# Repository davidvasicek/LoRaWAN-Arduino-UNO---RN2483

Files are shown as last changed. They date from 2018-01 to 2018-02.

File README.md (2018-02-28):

# LoRaWAN-Arduino-UNO---RN2483

### Cíl projektu

Tento projekt byl vytvořen za účelem testování LoRaWAN sítě v oblasti Ostravy, kterou v rámci svých cvičení realizují studenti předmětu Radiokomunikační technika/Rádiové sítě vyučovaného na Katedře telekomunikační techniky, VŠB-TU Ostrava.

V rámci tohoto projektu bylo vytvořeno 8 čidel založených na deskách LoRaWAN Arduino UNO s čipem RN2483 napájených stabilizovaným 3V3 napětím devíti voltové externí baterie a integrovaným MicroUSB konektorem. Každý takovýto modul vysílá prostřednictvím LoRaWAN sítě o frekvenci 868 MHz krátký textový řetězec obsahující svou identifikaci, která je směrována na LoRa Gateway (TTN-GW-VSB) a vizualizována v prostředí The Things Network (TTN). Na základě této komunikace je následně možné určit vysílající výkonovou úrověň daných senzorů a tím vytvořit reálnou mapu pokrytí LoRaWAN sítě dané oblasti.

Pro účely testování bylo zapotřebí obejít Duty Cycle modulu RN2483, který nám omezoval zasílání zpráv v kratších intervalech. Každý takovýto modul RN2483 obsahuje vnitřní čítač zabraňující porušení vysílajících oprávnění přesahující 1% vysílající hodiny. Proto byl modul opakovaně resetován, čímž byl vymazán i jeho vnitřní čítač a tím jsme umožnili testování v kratších časových intervalech.

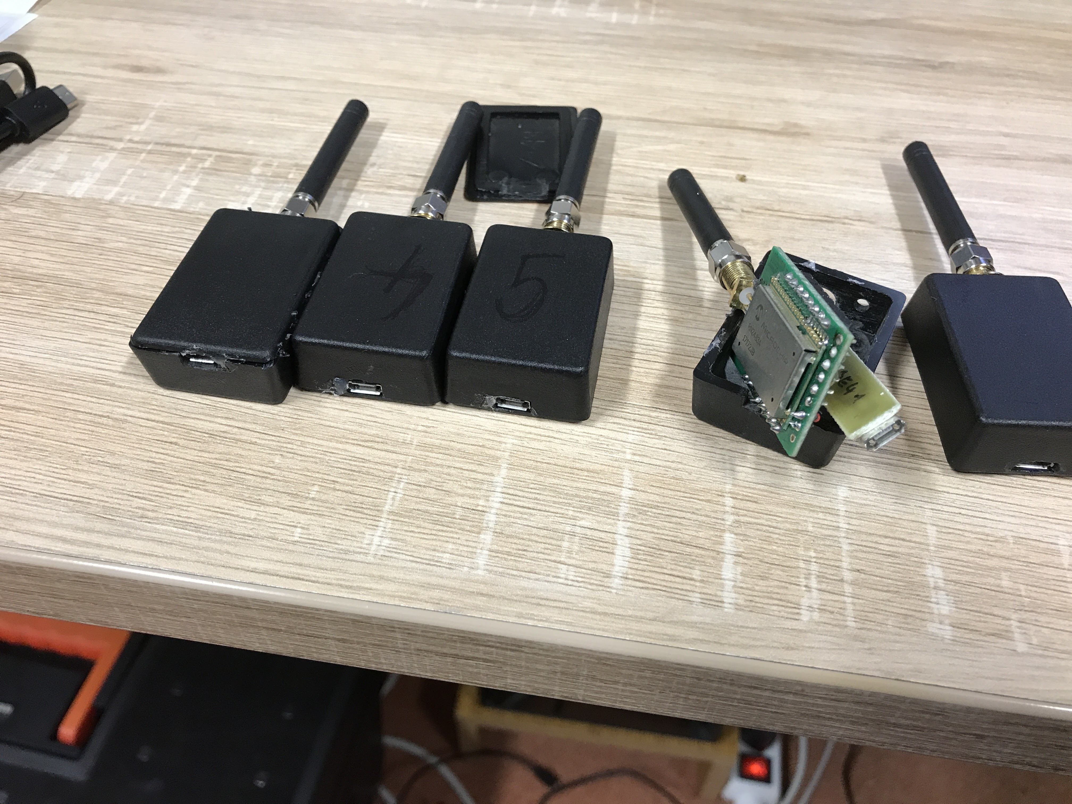
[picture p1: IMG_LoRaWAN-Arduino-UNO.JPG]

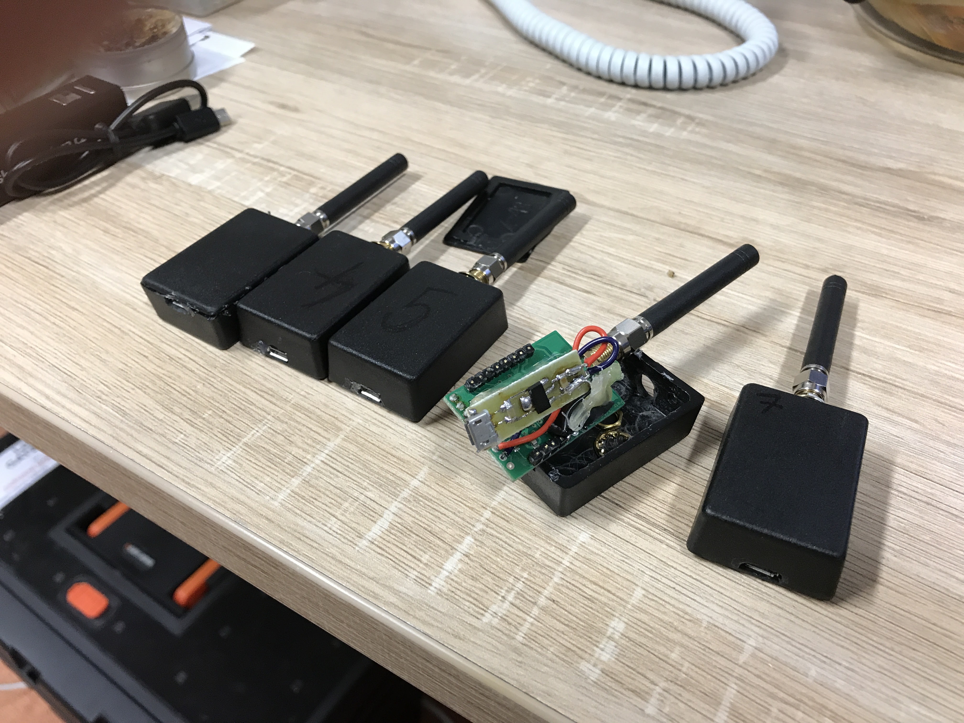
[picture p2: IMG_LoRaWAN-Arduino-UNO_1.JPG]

### Specifikace

LoRaWAN Arduino UNO je malý modulek, na jehož horní straně je transceiver RN2483 firmy Microchip, který je zkomunikovaný s procesorem ATmega328p ležícím na spodní straně desky. V procesoru je bootloader Arduino UNO (možno adaptovat na NANO). Modul je přímo přizpůsoben pro komunikaci v sítích LoRaWAN (více info na things.cz nebo na stránkách Českých Radiokomunikací a.s.). K dispozici jsou tato rozhraní: [1]
-	6 digitálních vstupů/výstupů
-	1 digitální vstup s přerušením pro low power režim
-	1 analogový vstup/výstup
-	vstup pro UART/USB převodník
-	anténní konektor SMA samice (na přání možno osadit U.FL IPX konektorem pro vyvedení antény pigtailem)

**Napájení:**
-	flash mód 5V
-	provozní mód 3,3V (bateriové napájení v rozmezí 2,4V až 4,1V)

**Naměřená spotřeba:**
-	power down mód cca 20uA
-	normální režim cca 25mA
-	vysílací špička cca 120mA

### Tutoriál

Výsledkem tohoto tutoriálu je čidlo založené na desce LoRaWAN Arduino UNO s vysílacím modulem RN2483 umožňující zasílaní krátkých zpráv prostřednictvím bezdrátové technologie LoRa. Tyto zprávy mohou obsahovat například informace o okolních teplotách získávány z externího teplotního senzoru, které je možné k desce LoRaWAN Arduino UNO připojit, nebo informace z mnoha jiných senzorů kompatibilních s touto deskou.

Kompletní tutoriál naleznete ve formátu .pdf [zde](https://github.com/davidvasicek/LoRaWAN-Arduino-UNO---RN2483/blob/master/LoRaWAN-Arduino-UNO---RN2483_tutorial.pdf)
                                                                                        
### Obsah adresáře

- **LoRa_RN5.brd** - DPS LoRaWAN Arduino UNO (Eagle)
- **LoRa_RN5.sch** - schéma LoRaWAN Arduino UNO (Eagle)
- **RN2483-Arduino-Library-master.zip** - knihovna pro RN2483 dostupná [zde](https://github.com/jpmeijers/RN2483-Arduino-Library)
- **LoRaWAN-Arduino-UNO---RN2483_code.ino** - kód pro Arduino IDE
- **LoRaWAN-Arduino-UNO---RN2483_tutorial.pdf** - tutoriál
- **LoRaDHT22** - ukázkový kód pro připojení teplotního čidla DHT22 k LoRaWAN Arduino UNO
- **IMG_LoRaWAN-Arduino-UNO.jpg** - foto vytvořených čidel
- **IMG_LoRaWAN-Arduino-UNO_1.jpg** - foto vytvořených čidel

### Užitečné odkazy

- Specifikace LoRaWAN Arduino UNO - RN2483 - e-shop [zde](https://www.arduinotech.cz/produkt/lorawan-arduino-uno/)
- Specifikace RN2483 [zde](http://ww1.microchip.com/downloads/en/DeviceDoc/50002346C.pdf)
- Popis technologie LoRa [zde](http://www.raycom.cz/data/article/filemanager/LoRa.pdf)
- Článek LPWAN - LoRaWAN, Sigfox - vítejte v IoT! [zde](https://www.arduinotech.cz/inpage/lpwan-lorawan-sigfox-vitejte-v-iot/)
- Článek LoRaWAN Arduino UNO s transceiverem RHF76 [zde](https://www.arduinotech.cz/inpage/lorawan-arduino-uno-s-transceiverem-rhf76/)

### Zdroje

- [1] [https://www.arduinotech.cz/produkt/lorawan-arduino-uno/](https://www.arduinotech.cz/produkt/lorawan-arduino-uno/)

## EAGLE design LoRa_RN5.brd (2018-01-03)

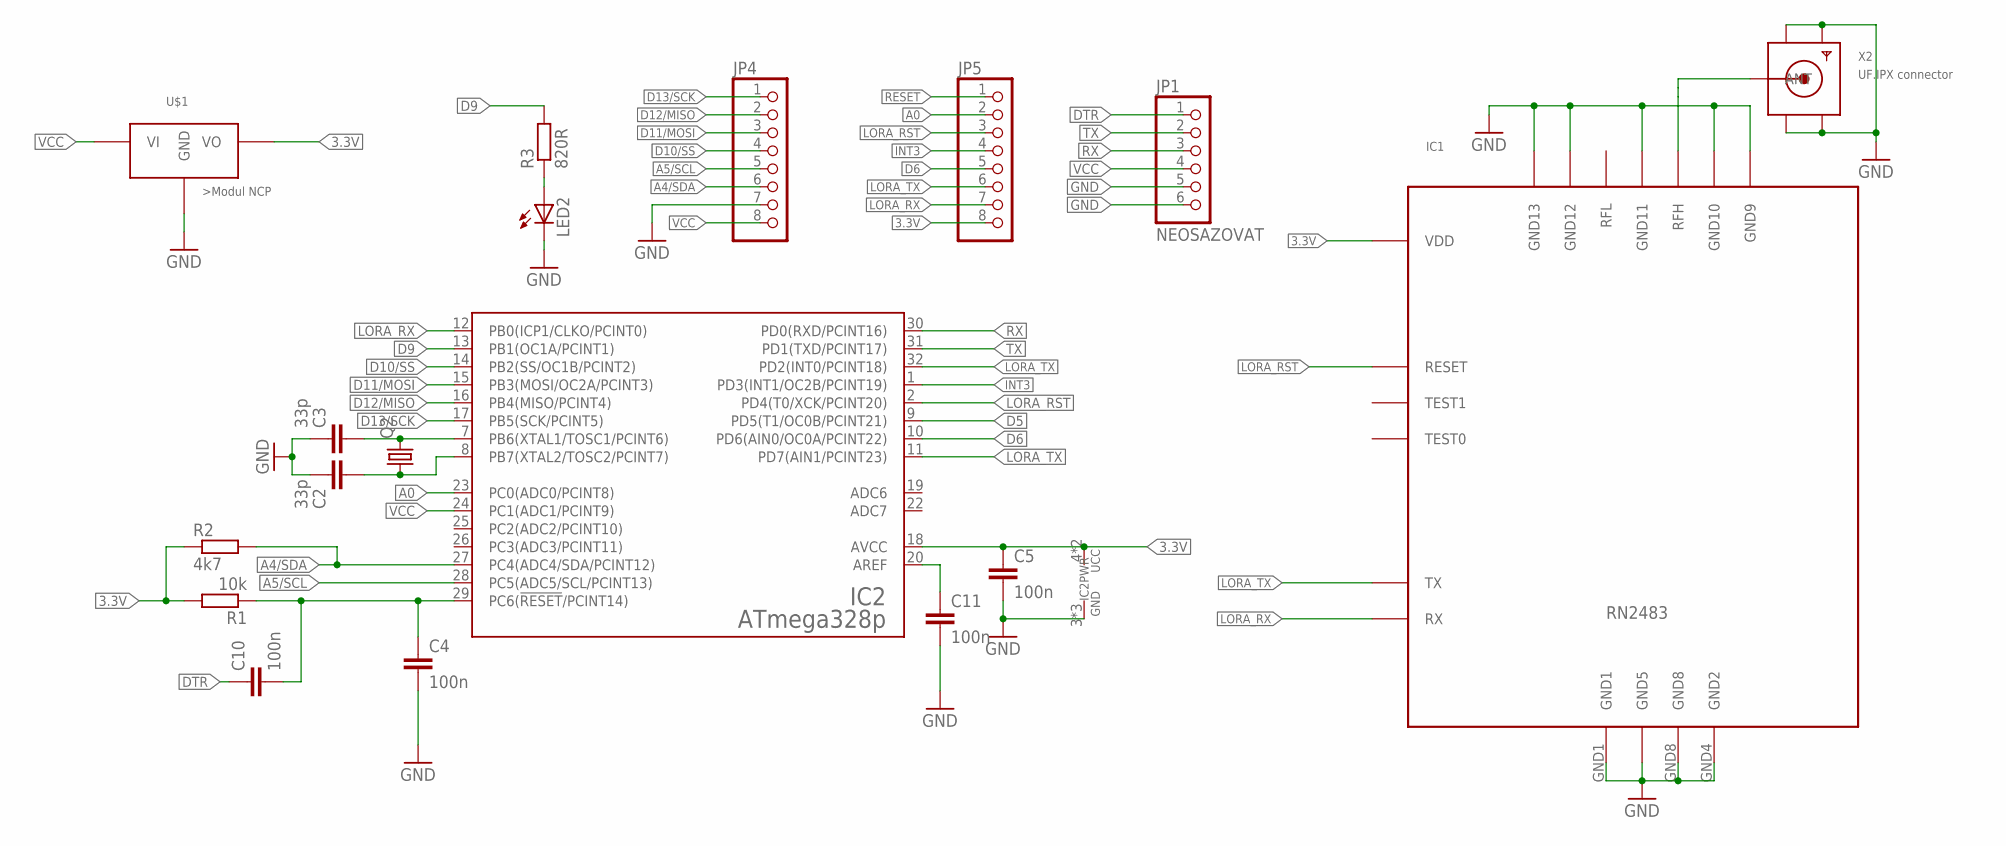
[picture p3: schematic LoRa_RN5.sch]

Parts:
C2, C3: 33p; C0805
C4, C5, C10, C11: 100n; C0805
IC1: RN2483_MIN; RN2483_2
IC2: ATmega328p; TQFP32-08
JP1: NEOSAZOVAT; 1X06
JP4, JP5: PINHD-1X8; 1X08
LED2: LEDCHIPLED_1206; CHIPLED_1206
Q2: CRYSTALCTS406; CTS406
R1: 10k; R0805
R2: 4k7; R0805
R3: 820R; R0805
U$1: NEOSAZOVAT; MOD_NCP1402
X2: UF.IPX connector; SMA_EDGELAUNCH_UFL

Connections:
3.3V: C5.1, IC1.VDD, IC2.4 (UCC), IC2.6 (UCC), IC2.18 (AVCC), JP5.8, R1.2, R2.1, U$1.VO
A0: IC2.23 (PC0(ADC0/PCINT8)), JP5.2
A4/SDA: IC2.27 (PC4(ADC4/SDA/PCINT12)), JP4.6, R2.2
A5/SCL: IC2.28 (PC5(ADC5/SCL/PCINT13)), JP4.5
D5: IC2.9 (PD5(T1/OC0B/PCINT21))
D6: IC2.10 (PD6(AIN0/OC0A/PCINT22)), JP5.5
D9: IC2.13 (PB1(OC1A/PCINT1)), R3.2
D10/SS: IC2.14 (PB2(SS/OC1B/PCINT2)), JP4.4
D11/MOSI: IC2.15 (PB3(MOSI/OC2A/PCINT3)), JP4.3
D12/MISO: IC2.16 (PB4(MISO/PCINT4)), JP4.2
D13/SCK: IC2.17 (PB5(SCK/PCINT5)), JP4.1
DTR: C10.1, JP1.1
GND: C2.1, C3.1, C4.2, C5.2, C11.2, IC1.GND1, IC1.GND4 (GND2), IC1.GND5, IC1.GND8, IC1.GND9, IC1.GND10, IC1.GND11, IC1.GND12, IC1.GND13, IC2.3 (GND), IC2.5 (GND), IC2.21 (GND), JP1.5, JP1.6, JP4.7, LED2.C, U$1.GND, X2.GND@1 (GND1), X2.GND@2 (GND2), X2.GND@3 (GND3), X2.GND@4 (GND4)
INT3: IC2.1 (PD3(INT1/OC2B/PCINT19)), JP5.4
LORA_RST: IC1.RESET, IC2.2 (PD4(T0/XCK/PCINT20)), JP5.3
LORA_RX: IC1.RX, IC2.12 (PB0(ICP1/CLKO/PCINT0)), JP5.7
LORA_TX: IC1.TX, IC2.11 (PD7(AIN1/PCINT23)), IC2.32 (PD2(INT0/PCINT18)), JP5.6
unnamed: IC1.RFH, X2.P (ANT)
unnamed: C2.2, IC2.8 (PB7(XTAL2/TOSC2/PCINT7)), Q2.1
unnamed: C3.2, IC2.7 (PB6(XTAL1/TOSC1/PCINT6)), Q2.3 (2)
unnamed: LED2.A, R3.1
unnamed: C11.1, IC2.20 (AREF)
RESET: C4.1, C10.2, IC2.29 (PC6(!RESET!/PCINT14)), JP5.1, R1.1
RX: IC2.30 (PD0(RXD/PCINT16)), JP1.3
TX: IC2.31 (PD1(TXD/PCINT17)), JP1.2
VCC: IC2.24 (PC1(ADC1/PCINT9)), JP1.4, JP4.8, U$1.VI

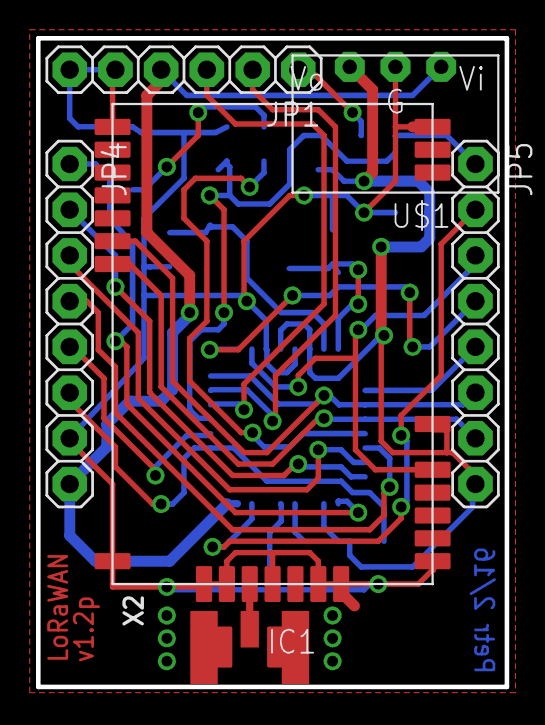
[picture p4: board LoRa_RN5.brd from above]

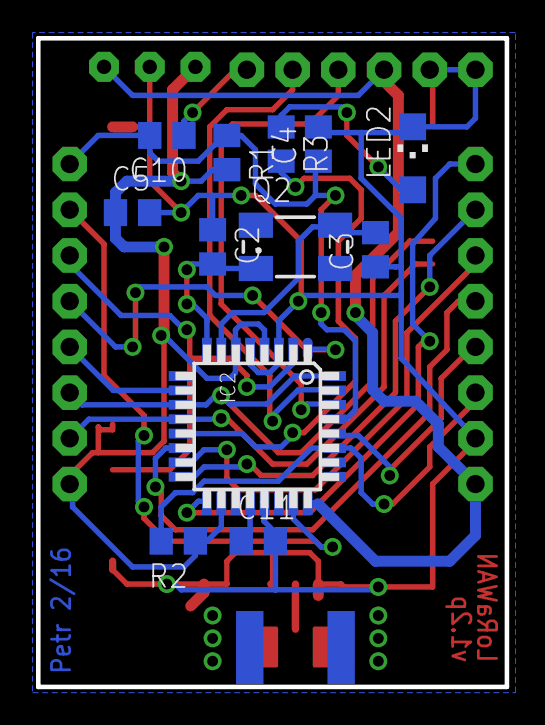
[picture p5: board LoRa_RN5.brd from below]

Board: 2 copper layers, 26.0 x 36.0 mm, 18 parts (12 on the bottom side), 25 nets.

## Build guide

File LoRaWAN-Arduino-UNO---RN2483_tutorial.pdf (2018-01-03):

## Tutoriál

# LoRaWAN Arduino UNO - RN2483

1) Připojení USB TTL (UART/FTDI) převodníku k desce LoRaWAN Arduino UNO

Z důvodu, že deska LoRaWAN Arduino UNO není osazena USB převodníkem, nelze ji přímo propojit s PC. Proto je nutné desku naprogramovat externím USB převodníkem, který slouží ke komunikaci mezi PC a zařízením s portem RS232 (sériové rozhraní), jinak také COM. Vhodný převodník je nutné volit tak, aby na něm byl přítomen DTR pin, potřebný pro RESET puls.

Tip: Pokud máte pouze USB převodník bez DTR pinu, mohli byste vytvořit RESETovací puls např. mikrospínacím tlačítkem (zapotřebí prostudovat).

Převodník lze zakoupit např. z těchto e-shopů:

- https://www.ptshop.cz/Prevodnik-USB-na-TTL-RS232-FTDI-FT232RL-d598.htm
- https://arduino-shop.cz/arduino/1747-breakout-board-usb-na-seriove-ic-ftdi-ft232rl-3-3v-5-5v-pro-arduino-1502365219.html (https://arduino-shop.cz/arduino/1747-breakout-board-usb-na-seriove-ic-ftdi-ft232rl-3-3v-5-5v-pro-arduino-1502365219.html)

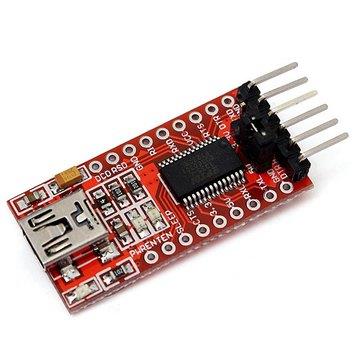
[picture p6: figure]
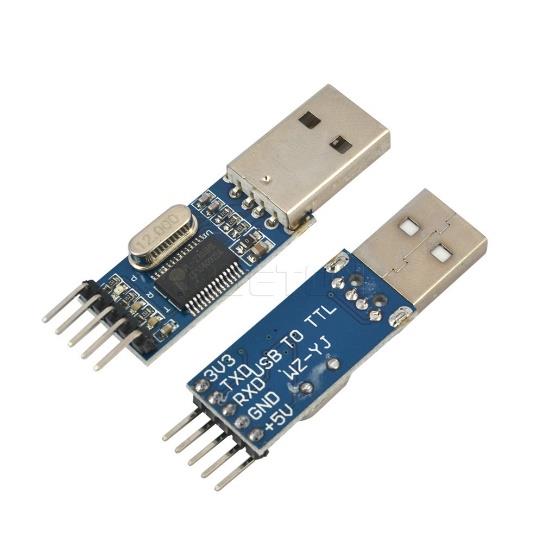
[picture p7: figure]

S DTR pinem | Bez DTR pinu
a) Připojte USB převodník k PC.
b) Spusťte správce zařízení (Start -> Ovládací panely -> Hardware a zvuk -> Správce zařízení) a zkontrolujte položku “Porty (COM a LPT)“, kde bychom měli najít námi připojené FTDI pod označením “COM(x)“, kde “x“ označuje číslo portu. Pokud takto označené FTDI nenajdeme, najdeme jej pravděpodobně v “Neznámá zařízení“ a to značí, že jej počítač neumí rozpoznat a budeme nuceni nainstalovat potřebné ovládače – bod c). Pokud PC převodník USB rozpoznal, přejděte k bodu d).

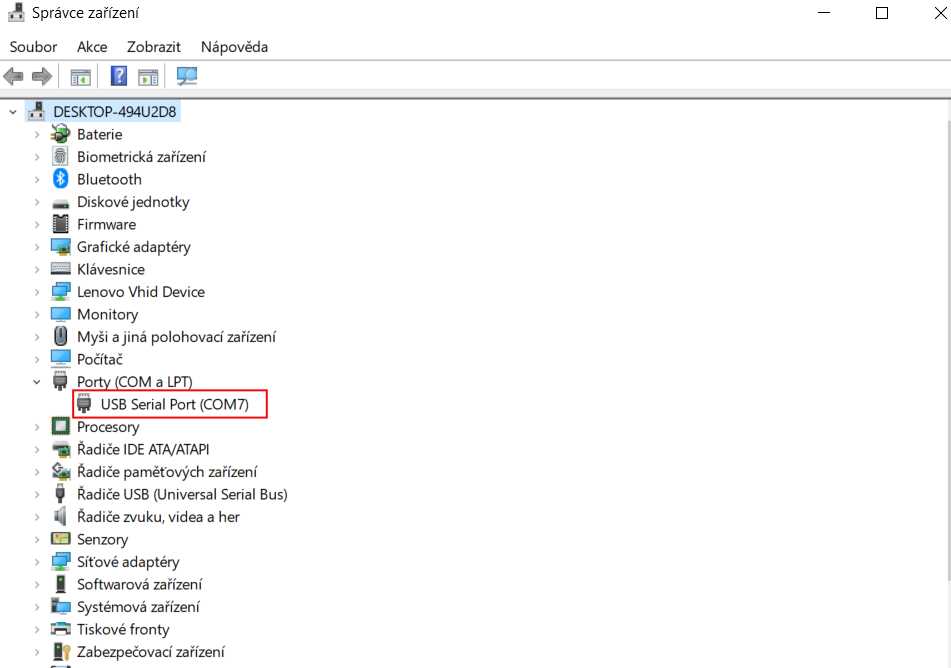
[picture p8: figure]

c) K instalaci ovládačů mi osobně byla nápomocná následující stránka (Win10), na které je uveden také postup, jak ovládače nainstalovat.

http://www.ifamilysoftware.com/news37.html

Po instalaci ovládačů restartujte PC, FTDI znovu připojte a opět ověřte správnost ovládačů. Pokud byla instalace neúspěšná, bude potřeba problém vyřešit hlubším bádáním.

d) Odpojte USB převodník od PC a propojte jej s LoRaWAN Arduino UNO dle následujícího zapojení:
LoRaWAN Arduino UNO | ---> | USB převodník
GND | ---> | GND
GND | ---> | CTS
VCC | ---> | VCC
RX | ---> | TX
TX | ---> | RX
DTR | ---> | DTR

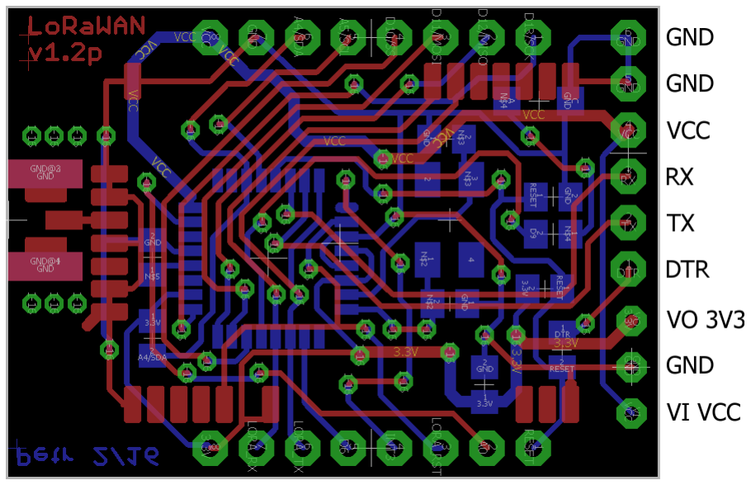
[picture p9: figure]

Pozn.: Výše uvedená DPS vyobrazuje pohled shora (pohled na modul a logo | ).
Pozn.: DPS je součásti tohoto adresáře pod označením LoRa_RN5.brd a lze ji otevřít například v programu Eagle.
e) V posledním kroku je potřeba na samotném převodníku pře-jumperovat výstupní napětí na 5V (ačkoli samotný LoRa WAN modul pracuje na napětí 3V3, v programovacím režimu je potřeba dodat 5V).

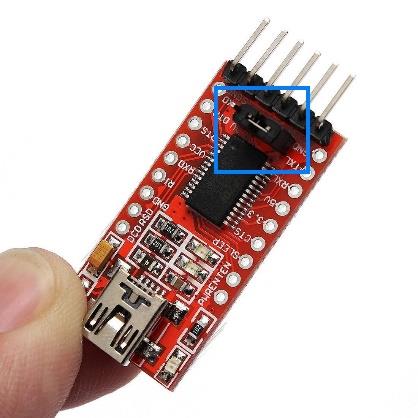
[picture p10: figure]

2) Nahrání kódu do LoRaWAN Arduino UNO (Windows)

Jakmile máme LoRaWAN Arduino UNO propojen s USB převodníkem, připojíme jej do PC a můžeme začít programovat. Pokud nemáme na svém PC nainstalovaný program Arduino IDE, učiňte tak stažením tohoto programu z následujících stránek a proveďte jeho instalaci.

https://www.arduino.cc/en/Main/Software

a) Po spuštění programu Arduino IDE je v prvé řadě zapotřebí zvolit desku, kterou budeme programovat (Nástroje -> Vývojová deska -> Arduino Uno), port, pod kterým bude
LoRaWAN Arduino UNO naprogramován (Nástroje -> Port -> COMx) a programátor (Nástroje -> Programátor -> USBtinyISP).

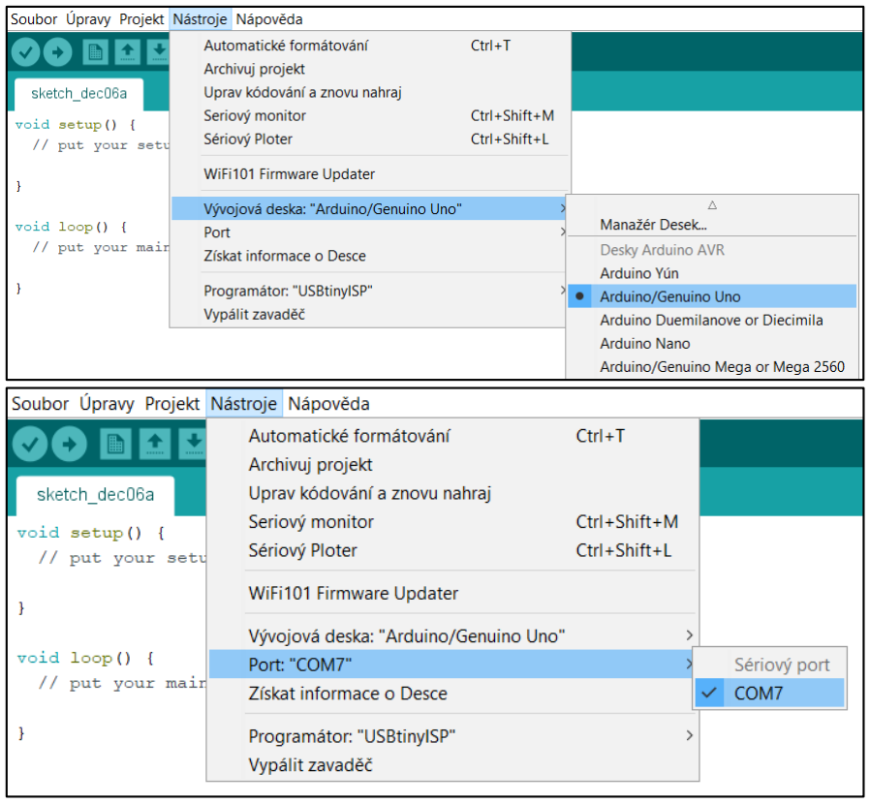
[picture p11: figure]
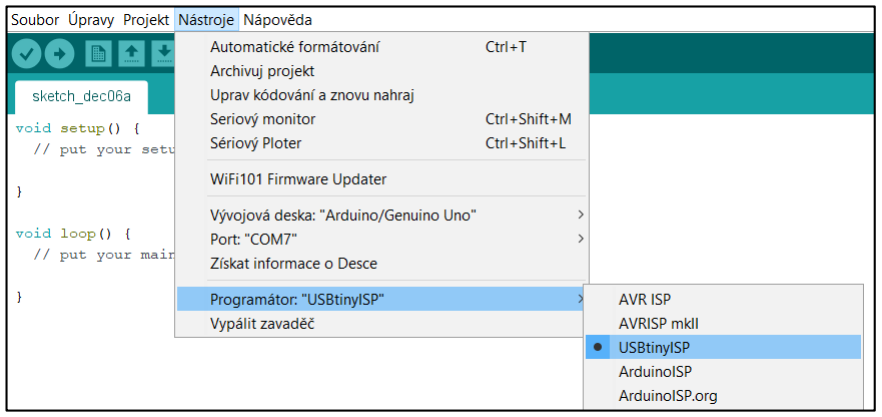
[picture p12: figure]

b) Vložte do editoru kód ze souboru LoRaWAN-Arduino-UNO---RN2483_code.ino obsaženého v tomto adresáři, nebo jej stáhněte a naimportujte (Soubor -> Otevřít -> LoRaWAN-Arduino-UNO---RN2483_code.ino). S tímto kódem budeme již nadále pracovat.
c) Po vložení kódu si můžeme všimnout, že je zde použita knihovna rn2xx3.h (#include <rn2xx3.h>). Tu budeme muset stáhnout z následujících stránek GitHubu a do projektu naimportovat.

https://github.com/jpmeijers/RN2483-Arduino-Library

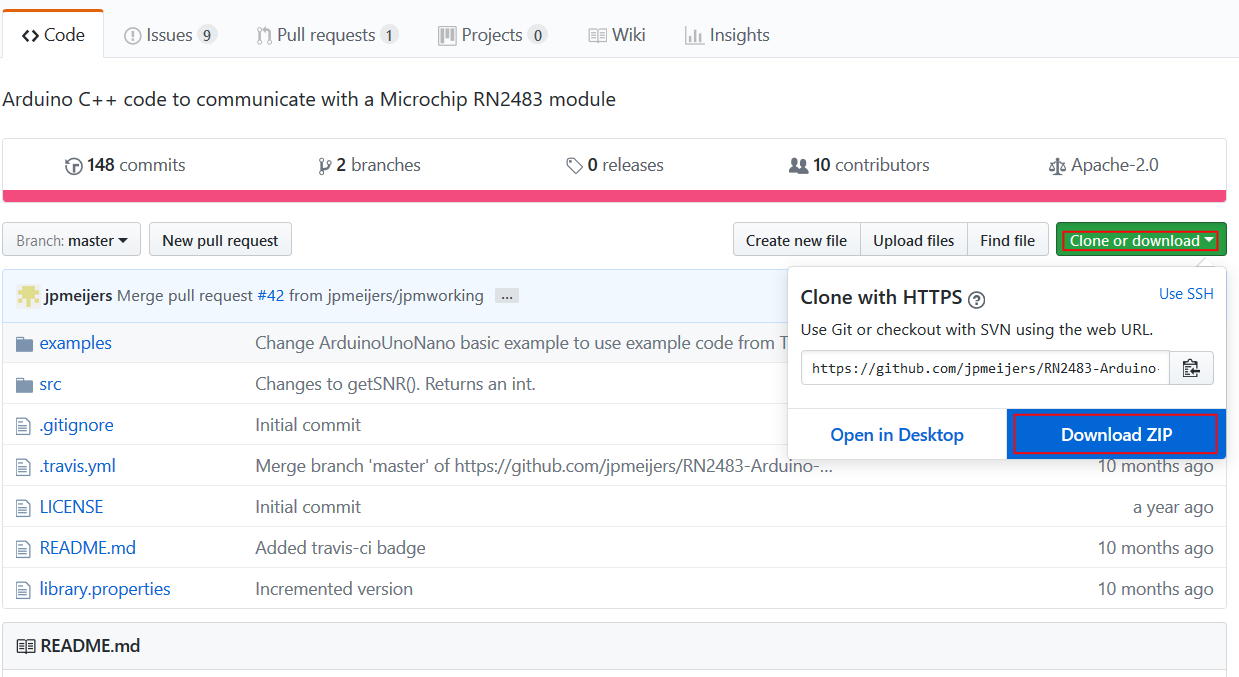
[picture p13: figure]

Nyní je potřeba knihovnu naimportovat do našeho projektu (Projekt -> Přidat knihovnu -> Přidat .ZIP Knihovnu -> RN2483-Arduino-Library-master.zip)

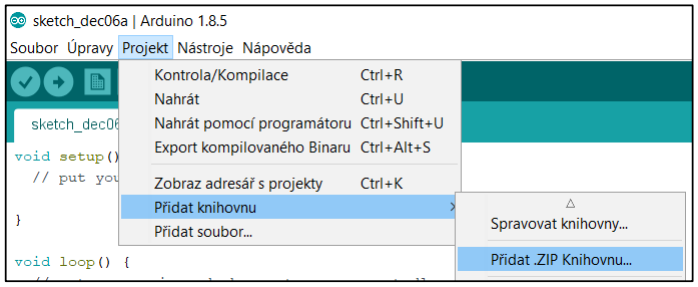
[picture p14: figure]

d) Úprava kódu: Pro správný chod programu, je nutné v kódu změnit následující údaje:

const char *appEui = "**********************";
const char *appKey = "********************************************";

kde znaky hvězdičky nahraďte za správné klíče. Tyto klíče naleznete: https://console.thethingsnetwork.org/ -> Applications -> [vase_aplikace] -> Devices -> [vase_zarizeni] -> Overview (v dolní části stránky).

Pozn.: Je zapotřebí mít na The Things Network (TTN) ověřený účet a již vytvořenou aplikaci s přidanými zařízeními (těmito postupy se návod nezabývá)

myLora.tx("text");

kde text nahraďte svým vlastním textem (například s údaji o teplotě z teplotního senzoru).

e) Nahrání kódu: Jakmile máte kód upravený, nezbývá než jej zkompilovat a pomocí USB převodníku do LoRaWAN Arduino UNO desky nahrát. To proveďte pomocí tlačítka:

Jestliže se při nahrávání neobjevila žádná chyba a kód byl do desky nahrán, objeví se v dolní levé části modrého pruhu programu zpráva konec nahrávání.

f) Získání DevEUI zařízení: Z důvodu, že používáme registraci prostřednictvím OTAA, budeme nuceni vytěžit ze samotného čipu RN2483 jeho DevEUI. Tento jedinečný identifikátor nám je vypisován po sériové lince během procesu inicializace rádia a my si jej tudíž můžeme přečíst v sériovém monitoru COMu, ke kterému je deska připojena (Nástroje -> Sériový monitor), odkud DevEUI zkopírujte.

Tip: Pokud se vám v sériovém monitoru nebude zobrazovat čitelný text, popřípadě žádný, budete nuceni změnit přenosovou rychlost, na které sériová linka vysílá. To provedete v dolní pravé části sériového monitoru, kde nastavte přenosovou rychlost na 57600 baudů, popř. na 9600 baudů.

Jakmile máte DevEUI získáne, bude potřeba jej vložit do vašeho zařízení v aplikaci TTN. (https://console.thethingsnetwork.org/ -> Applications -> [vase_aplikace] -> Devices -> [vase_zarizeni] -> Settings (vložte do “Device EUI“ a ztvrďte tlačítkem “save“ v dolní části stránky))

g) Testování: Přejděte do záložky Data (https://console.thethingsnetwork.org/ -> Applications -> [vase_aplikace] -> Devices -> [vase_zarizeni] -> Data) a sledujte přijímaná data z vašeho LoRAWAN modulu.

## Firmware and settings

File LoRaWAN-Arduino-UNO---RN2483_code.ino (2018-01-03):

/*
 * Author: JP Meijers
 * Date: 2016-02-07
 * Previous filename: TTN-Mapper-TTNEnschede-V1
 *
 * This program is meant to be used with an Arduino UNO or NANO, conencted to an RNxx3 radio module.
 * It will most likely also work on other compatible Arduino or Arduino compatible boards, like The Things Uno, but might need some slight modifications.
 *
 * Transmit a one byte packet via TTN. This happens as fast as possible, while still keeping to
 * the 1% duty cycle rules enforced by the RN2483's built in LoRaWAN stack. Even though this is
 * allowed by the radio regulations of the 868MHz band, the fair use policy of TTN may prohibit this.
 *
 * CHECK THE RULES BEFORE USING THIS PROGRAM!
 *
 * CHANGE ADDRESS!
 * Change the device address, network (session) key, and app (session) key to the values
 * that are registered via the TTN dashboard.
 * The appropriate line is "myLora.initABP(XXX);" or "myLora.initOTAA(XXX);"
 * When using ABP, it is advised to enable "relax frame count".
 *
 * Connect the RN2xx3 as follows:
 * RN2xx3 -- Arduino
 * Uart TX -- 10
 * Uart RX -- 11
 * Reset -- 12
 * Vcc -- 3.3V
 * Gnd -- Gnd
 *
 * If you use an Arduino with a free hardware serial port, you can replace
 * the line "rn2xx3 myLora(mySerial);"
 * with     "rn2xx3 myLora(SerialX);"
 * where the parameter is the serial port the RN2xx3 is connected to.
 * Remember that the serial port should be initialised before calling initTTN().
 * For best performance the serial port should be set to 57600 baud, which is impossible with a software serial port.
 * If you use 57600 baud, you can remove the line "myLora.autobaud();".
 *
 */
#include <rn2xx3.h>
#include <SoftwareSerial.h>

SoftwareSerial mySerial(7, 8); // RX, TX

//create an instance of the rn2xx3 library,
//giving the software serial as port to use
rn2xx3 myLora(mySerial);

// constant
int8_t LED_STATUS = 6; // externi LED
int8_t LED_RESIST = 9; // integrovana LED

int i = 0;

// the setup routine runs once when you press reset:
void setup()
{

  pinMode(4, OUTPUT); // output reset rn2483 pin
    
  pinMode(LED_STATUS, OUTPUT); //output LED pin
  pinMode(LED_RESIST, OUTPUT); //output LED pin
  digitalWrite(LED_RESIST, HIGH); 
  led_on();

  // Open serial communications and wait for port to open:
  Serial.begin(57600); //serial port to computer
  mySerial.begin(9600); //serial port to radio
  Serial.println("Startup");

  initialize_radio();

  //transmit a startup message
  myLora.tx("TTN Mapper on TTN Enschede node");

  led_off();

  delay(2000);
}

void initialize_radio()
{
  //reset rn2483 RE / 14
  pinMode(4, OUTPUT);
  digitalWrite(4, LOW);
  delay(500);
  digitalWrite(4, HIGH);

  delay(100); //wait for the RN2xx3's startup message
  mySerial.flush();

  //Autobaud the rn2483 module to 9600. The default would otherwise be 57600.
  myLora.autobaud();

  //check communication with radio
  String hweui = myLora.hweui();
  while(hweui.length() != 16)
  {
    Serial.println("Communication with RN2xx3 unsuccessful. Power cycle the board.");
    Serial.println(hweui);
    delay(10000);
    hweui = myLora.hweui();
  }

  //print out the HWEUI so that we can register it via ttnctl
  Serial.println("When using OTAA, register this DevEUI: ");
  Serial.println(myLora.hweui());
  Serial.println("RN2xx3 firmware version:");
  Serial.println(myLora.sysver());

  //configure your keys and join the network
  Serial.println("Trying to join TTN");
  bool join_result = false;

  /*
   * ABP: initABP(String addr, String AppSKey, String NwkSKey);
   * Paste the example code from the TTN console here:
   */
   
  //const char *devAddr = "02017201";
  //const char *nwkSKey = "AE17E567AECC8787F749A62F5541D522";
  //const char *appSKey = "8D7FFEF938589D95AAD928C2E2E7E48F";

  //join_result = myLora.initABP(devAddr, appSKey, nwkSKey);

  /*
   * OTAA: initOTAA(String AppEUI, String AppKey);
   * If you are using OTAA, paste the example code from the TTN console here:
   */
  
  const char *appEui = "**********************";
  const char *appKey = "********************************************";

  join_result = myLora.initOTAA(appEui, appKey);

  while(!join_result)
  {
    Serial.println("Unable to join. Are your keys correct, and do you have TTN coverage?");
    delay(20000); //delay a minute before retry RE / 10s
    join_result = myLora.init();
  }
  Serial.println("Successfully joined TTN");

}

// the loop routine runs over and over again forever:
void loop()
{
    led_on();

    i++;
    
    Serial.println("TXing");
    myLora.tx("text"); //one byte, blocking function

    led_off();

    if(i==6){

      //initialize_radio(); // reset rn2483 - vymaze citac pro duty cycle

      i=0;
      
    }

    delay(120000); // interval, ve kterem se zpravy odesilaji 120 sec
}

void led_on()
{
  digitalWrite(LED_RESIST, HIGH);
}

void led_off()
{
  digitalWrite(LED_RESIST, LOW);
}
